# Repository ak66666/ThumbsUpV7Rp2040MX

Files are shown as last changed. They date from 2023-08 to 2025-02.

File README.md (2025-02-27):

# ThumbsUp! v7 RP2040-based keyboard for MX switches

Multilevel 56/58 Key Split Contoured Keyboard.
2- or 3-key Thumb Cluster

* RP2040 is soldered on the boards.
* TRS (3-wire) audio cable to connect the halves.
* Hot swap sockets for MX switches.
* USB-C connectors.
* Connects to computer from either side, halves could be used separately.
* 3 different layouts for the 3-key cluster.

Board needs 3D printed switch plates: https://github.com/ak66666/ThubmsUpSwitchPlates

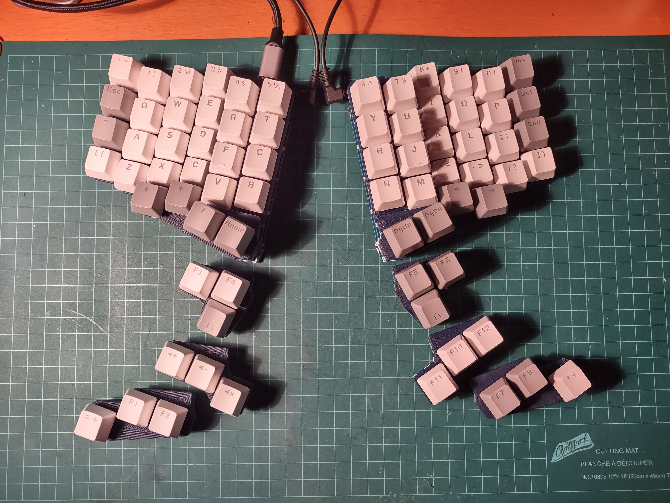
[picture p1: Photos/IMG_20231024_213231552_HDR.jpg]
Main view

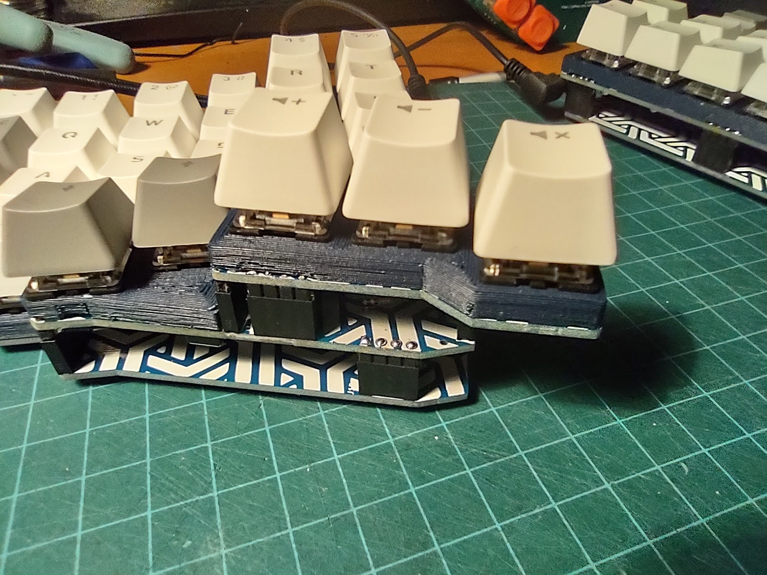
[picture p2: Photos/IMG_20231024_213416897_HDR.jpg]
Some keys are tucked under the middle PCB


Other pictures in Photos folder.

# Firmware

Please refer to this article:
https://thumbsupkeyboards.blogspot.com/2024/02/source-files-and-default-firmware.html

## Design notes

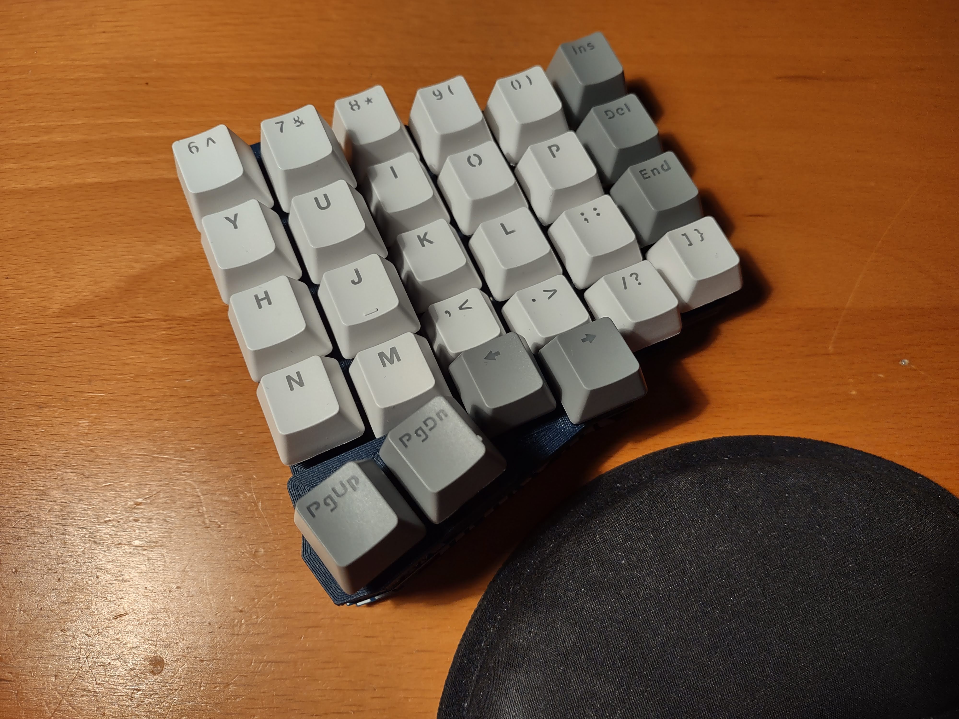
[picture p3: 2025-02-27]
Photos/IMG_20231021_212901962_HDR.jpg

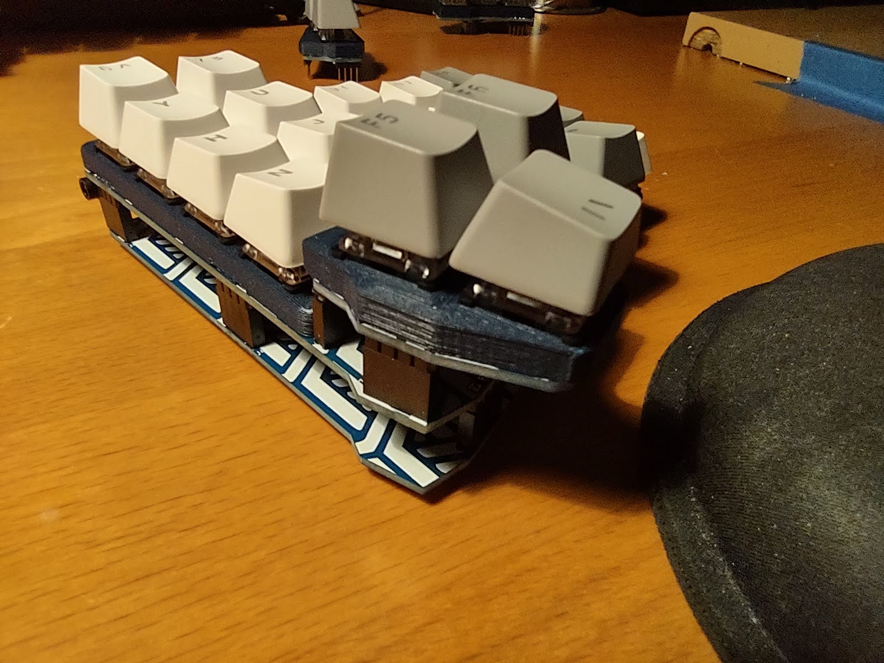
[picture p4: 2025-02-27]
Photos/IMG_20231021_213013907_HDR.jpg

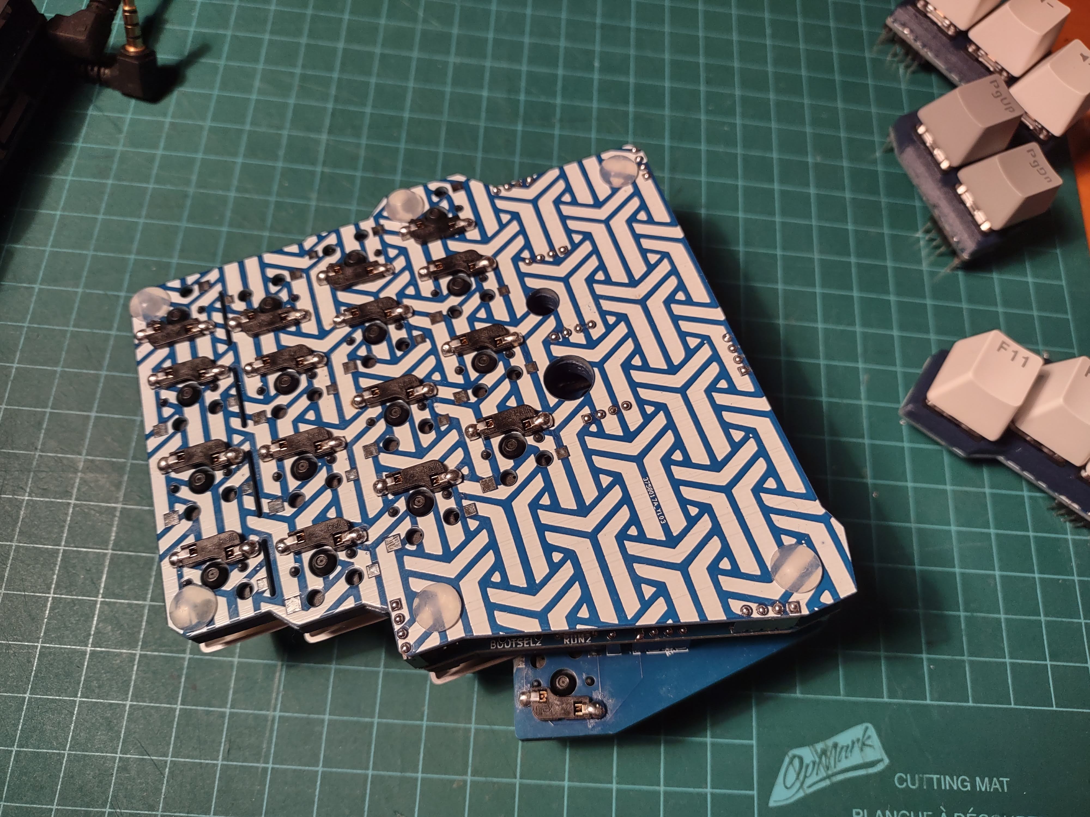
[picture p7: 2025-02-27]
Photos/IMG_20231025_093201816_HDR.jpg

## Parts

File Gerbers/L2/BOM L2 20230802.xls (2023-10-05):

Comment | Designator | Footprint | JLCPCB Part #
W25Q128JVSIM | IC2 | SOIC127P790X216-8N | C2613930
USB_C_Receptacle_USB2.0 | J32 | USB_C_Receptacle_Palconn_UTC16-G | C2927037
27pF | C5,C4 | C_0402_1005Metric | C1557
AMS1117-3.3_SOT223 | U1 | SOT229P700X180-4N | C6186
27.4 | R2,R1 | R_0402_1005Metric | C274349
10uF | C9 | C_0402_1005Metric | C15525
0.1uF | C17,C16,C15,C14,C13,C10,C7,C6,C2 | C_0402_1005Metric | C1525
5.1K | R9,R8,R4 | R_0402_1005Metric | C25905
100uF | C11 | C_1210_3225Metric | C16133
1uF | C12,C3 | C_0402_1005Metric | C52923
Polyfuse | F1 | Fuse_1206_3216Metric | C2836286
1k | R6 | R_0402_1005Metric | C11702
RP2040 | IC1 | QFN40P700X700X90-57N-D | C2040
10K | R3,R7 | R_0402_1005Metric | C25744
ABLS-12.000MHZ-B4-T | Y1 | HC-49S-SMD | C2901753

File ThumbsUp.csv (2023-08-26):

Id | Designator | Package | Quantity | Designation | Supplier and ref
1 | RUN,BOOTSEL | TL1016AAF220QG | 2 | TL1016AAF220QG
2 | IC1 | QFN40P700X700X90-57N-D | 1 | RP2040
3 | D25,D44,D43,D42,D41,D40,D39,D38,D37,D36,D35,D34,D33,D32,D31,D30,D29,D28,D27,D26,D24,D23,D22,D21,D20,D19,D18,D17,D16,D15,D14,D13,D12,D11,D10,D9,D8,D7,D6,D5,D4,D3,D2,D1 | D_SOD-123 | 44 | D_Small
4 | Y1 | HC%2f49US-(AT49)_1 | 1 | ABLS-12.000MHZ-B4-T
5 | R3 | R_0805_2012Metric | 1 | 10k
6 | IC2 | SOIC127P790X216-8N | 1 | W25Q128JVSIM
7 | C9,C11 | C_0805_2012Metric | 2 | 10uF
8 | C7,C6,C2,C1,C17,C16,C15,C14,C13,C10 | C_0805_2012Metric | 10 | 0.1uF
9 | C5,C4 | C_0805_2012Metric | 2 | 27pF
10 | C3,C12 | C_0805_2012Metric | 2 | 1uF
11 | U1 | SOT-223-3_TabPin2 | 1 | NCP1117-3.3_SOT223
12 | R7 | R_0805_2012Metric | 1 | DNF
13 | R6 | R_0805_2012Metric | 1 | 1k
14 | R5,R4 | R_0805_2012Metric | 2 | 4.7k
15 | R2,R1 | R_0805_2012Metric | 2 | 27.4
16 | F1 | Fuse_1206_3216Metric | 1 | Polyfuse
17 | USB1 | Molex-0548190589 | 1 | Molex-0548190589
18 | J27,J24,J25,J26,J6,J4 | PinHeader_1x04_P2.54mm_Vertical | 6 | Conn_01x04_Male
19 | J18,J10,J14 | PinHeader_1x04_P2.54mm_Vertical | 3 | Raiser_Male
20 | MX38 | Kailh_socket_PG1350_optional | 1 | SwMENU
21 | MX27 | Kailh_socket_PG1350_optional | 1 | SwU
22 | MX28 | Kailh_socket_PG1350_optional | 1 | SwJ
23 | MX29 | Kailh_socket_PG1350_optional | 1 | SwM
24 | MX34 | Kailh_socket_PG1350_optional | 1 | SwRALT
25 | J20,J21,J22,J23 | PinSocket_1x04_P2.54mm_Vertical | 4 | Conn_01x04_Female
26 | MX15 | Kailh_socket_PG1350_optional | 1 | SwR
27 | MX24 | Kailh_socket_PG1350_optional | 1 | SwH
28 | MX10 | Kailh_socket_PG1350_optional | 1 | SwLWIN
29 | MX14 | Kailh_socket_PG1350_optional | 1 | SwLALT
30 | MX17 | Kailh_socket_PG1350_optional | 1 | SwV
31 | MX25 | Kailh_socket_PG1350_optional | 1 | SwN
32 | MX19 | Kailh_socket_PG1350_optional | 1 | SwT
33 | MX21 | Kailh_socket_PG1350_optional | 1 | SwB
34 | MX20 | Kailh_socket_PG1350_optional | 1 | SwG
35 | MX23 | Kailh_socket_PG1350_optional | 1 | SwY
36 | MX16 | Kailh_socket_PG1350_optional | 1 | SwF
37 | J15,J11 | PinSocket_1x04_P2.54mm_Vertical | 2 | Raiser_Female

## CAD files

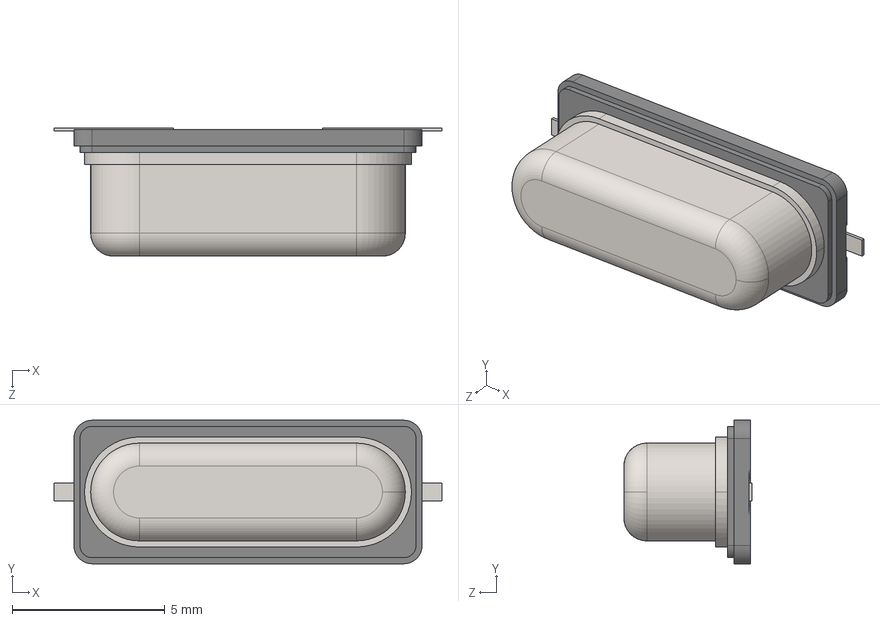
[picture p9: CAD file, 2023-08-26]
ABLS-12.000MHZ-B4-T/3D/ABLS-12.000MHZ-B4-T.stp
12.7 x 4.70 x 4.20 mm

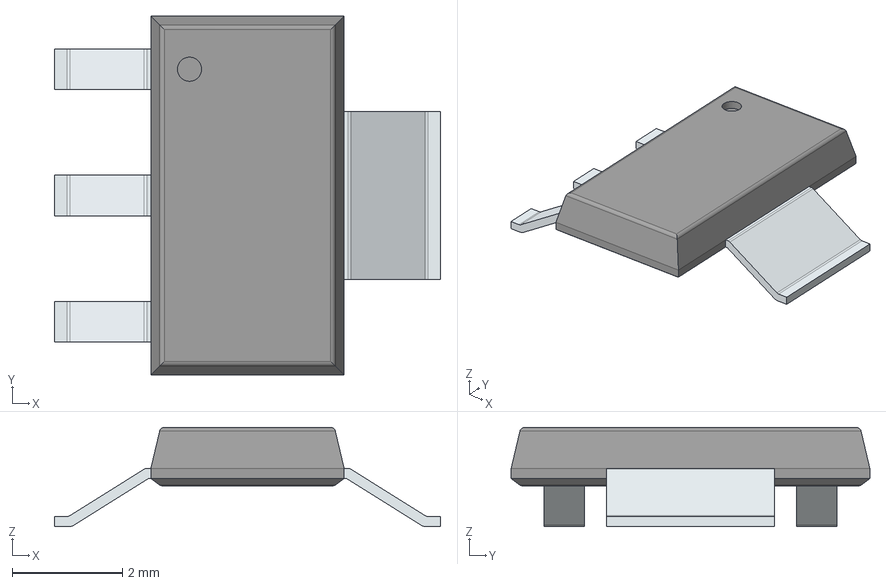
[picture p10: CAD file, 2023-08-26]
AMS1117-3.3/3D/AMS1117-3.3.stp
7.00 x 6.50 x 1.80 mm
PinsArrayL
FilletPinR

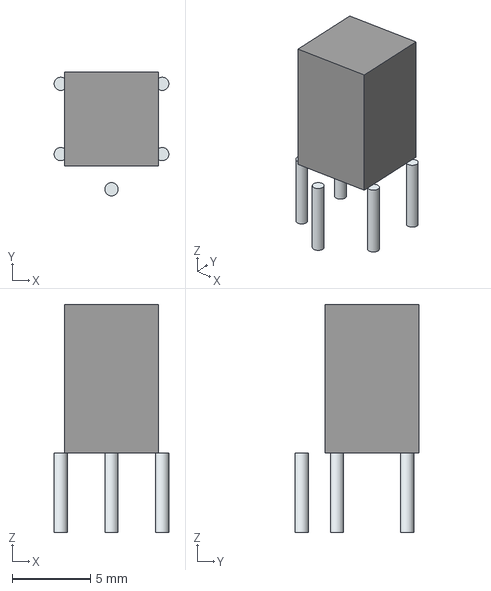
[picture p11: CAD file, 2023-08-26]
LIB_BUTT-4/BUTT-4/3D/BUTT-4.stp
7.35 x 7.92 x 14.6 mm
Leads x 5

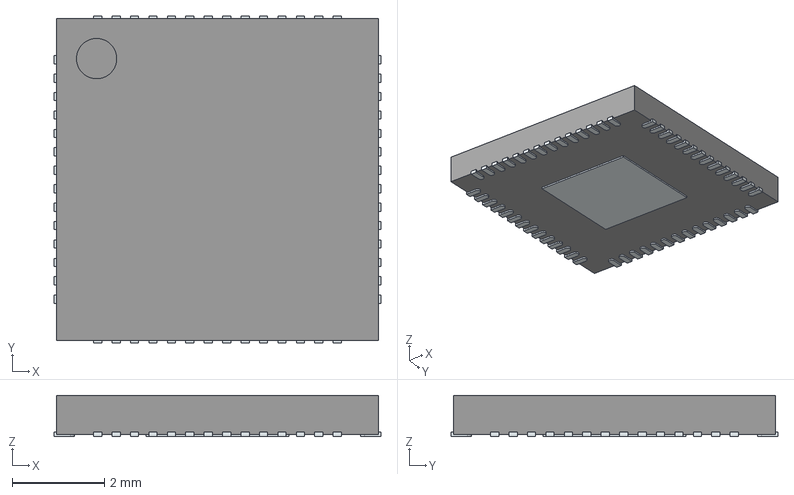
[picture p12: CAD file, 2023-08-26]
RP2040/3D/RP2040.stp
7.10 x 7.10 x 0.9 mm
ThermalPin
PinsArrayLR
PinsArrayTB

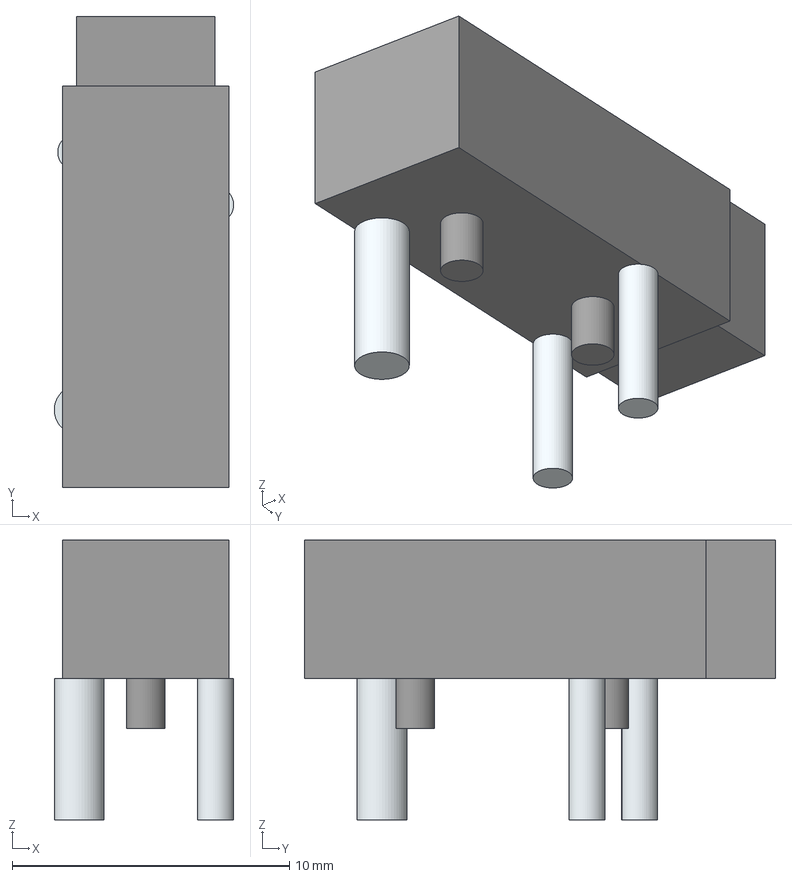
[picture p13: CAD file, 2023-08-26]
STX-3501-3N/3D/STX-3501-3N.stp
6.47 x 17.0 x 10.1 mm
Lugs
Leads

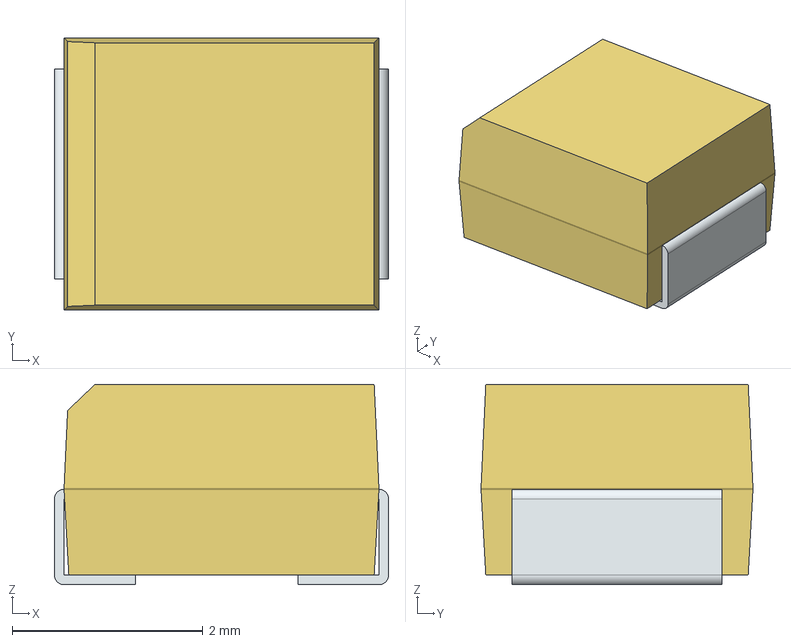
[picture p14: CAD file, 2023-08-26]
TAJB107K006RNJV/3D/TAJB107K006RNJV.stp
3.50 x 2.85 x 2.10 mm
FilletPin1
FilletPin2

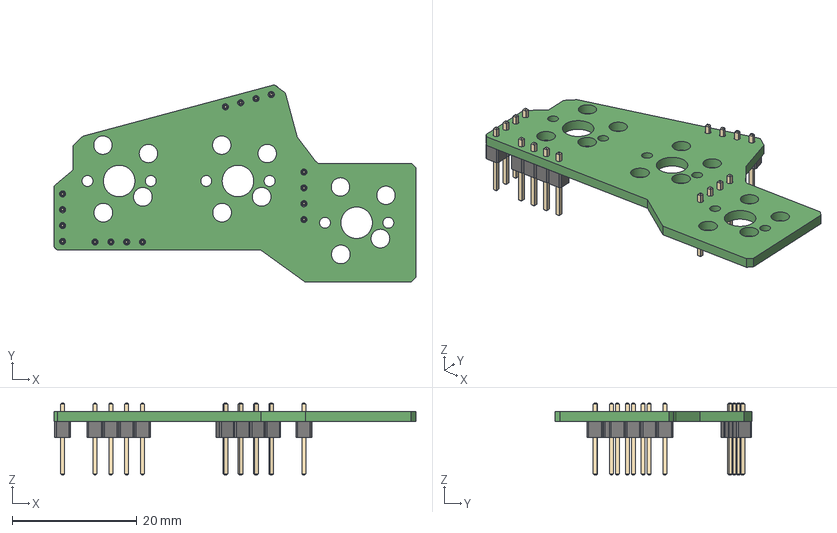
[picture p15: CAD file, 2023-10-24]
ThumbsUp.step
58.1 x 31.7 x 11.5 mm

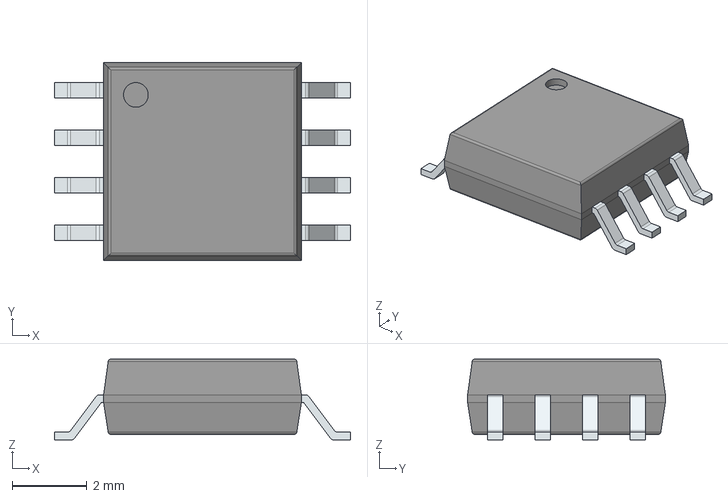
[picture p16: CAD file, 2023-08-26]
W25Q128JVSIM/3D/W25Q128JVSIM.stp
7.90 x 5.28 x 2.16 mm
PinsArrayLR

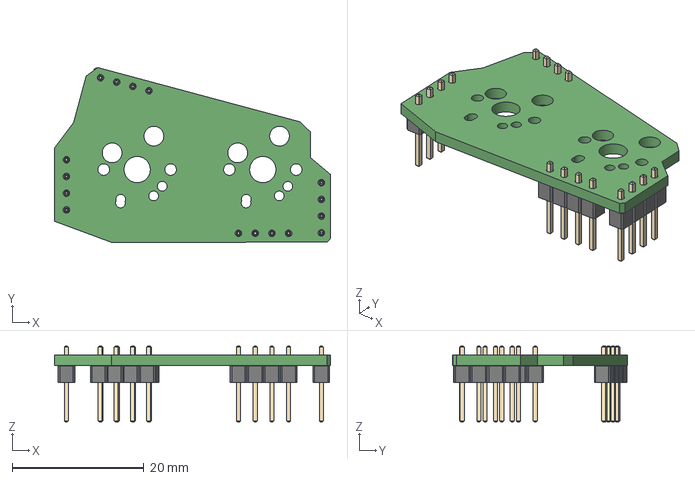
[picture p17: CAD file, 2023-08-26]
ThumbsUp 3.step
41.9 x 26.6 x 11.5 mm

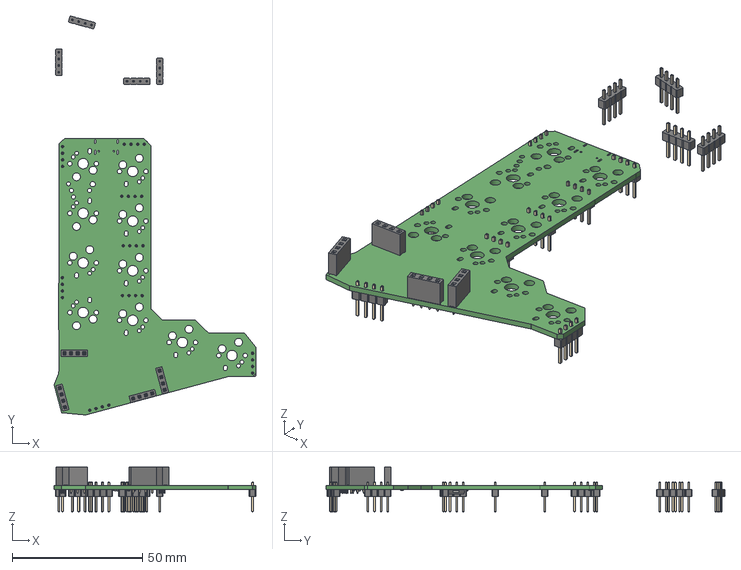
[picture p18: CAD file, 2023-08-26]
ThumbsUp 2.step
77.5 x 153.2 x 17.2 mm

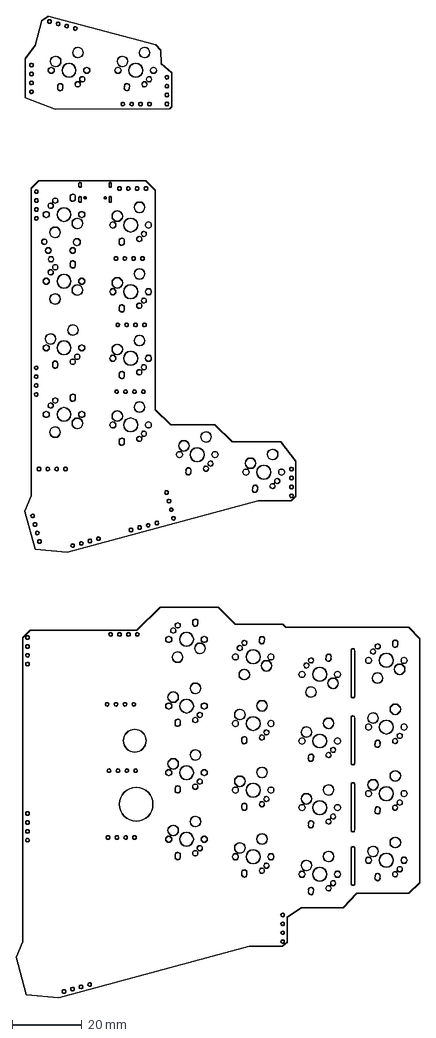
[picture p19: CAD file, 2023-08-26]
Outline.dxf
115.4 x 280.8 mm

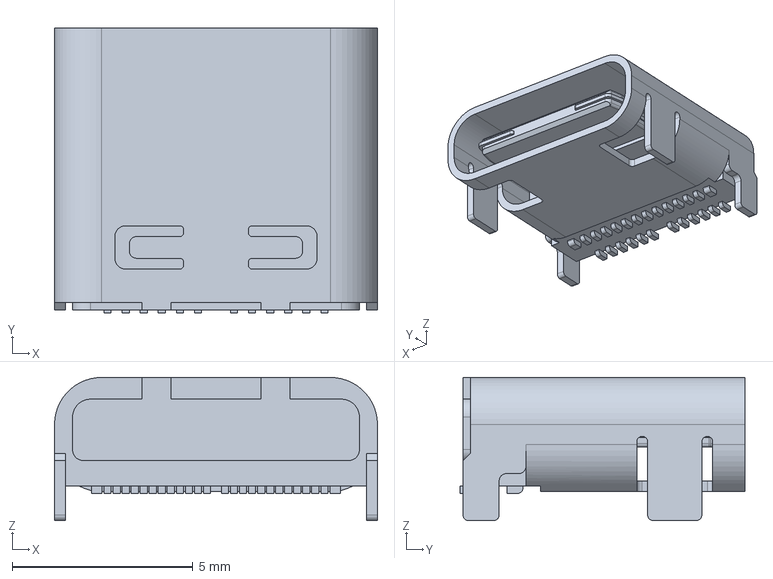
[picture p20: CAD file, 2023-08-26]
105450-0101/3D/105450-0101.stp
8.94 x 7.90 x 3.96 mm

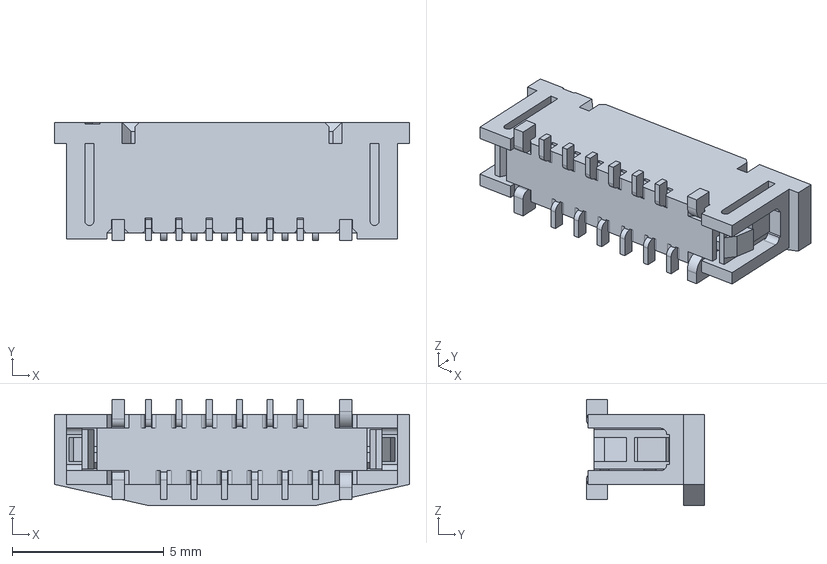
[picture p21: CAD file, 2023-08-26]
Molex 52559-1233/52559-1233/3D/52559-1233.stp
11.7 x 3.90 x 3.50 mm

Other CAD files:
Outline/Case v7 v5.3mf
ABLS-12.000MHZ-B4-T/Allegro/hc_49us-_at49__1.psm
ABLS-12.000MHZ-B4-T/DEHDL/abls_12.000mhz_b4_t/chips/chips.prt
AMS1117-3.3/Allegro/sot229p700x180-4n.psm
AMS1117-3.3/DEHDL/ams1117_3.3/chips/chips.prt
EVQ-P7B01P/Allegro/evqp7b01p.psm
EVQ-P7B01P/DEHDL/evq_p7b01p/chips/chips.prt
LIB_BUTT-4/BUTT-4/Allegro/butt4.psm
LIB_BUTT-4/BUTT-4/DEHDL/butt_4/chips/chips.prt
Molex 52559-1233/52559-1233/Allegro/525591233.psm
Molex 52559-1233/52559-1233/DEHDL/52559_1233/chips/chips.prt
Outline/Case v7 v5.f3d
Outline/Case v7 v5.ipt
Outline/Case v7 v5.skp
RP2040/Allegro/qfn40p700x700x90-57n-d.psm
RP2040/DEHDL/rp2040/chips/chips.prt
STX-3501-3N/Allegro/stx35013n.psm
STX-3501-3N/DEHDL/stx_3501_3n/chips/chips.prt
TAJB107K006RNJV/Allegro/cappm3528x210n.psm
TAJB107K006RNJV/DEHDL/tajb107k006rnjv/chips/chips.prt
TL1016AAF220QG/Allegro/tl1016aaf220qg.psm
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

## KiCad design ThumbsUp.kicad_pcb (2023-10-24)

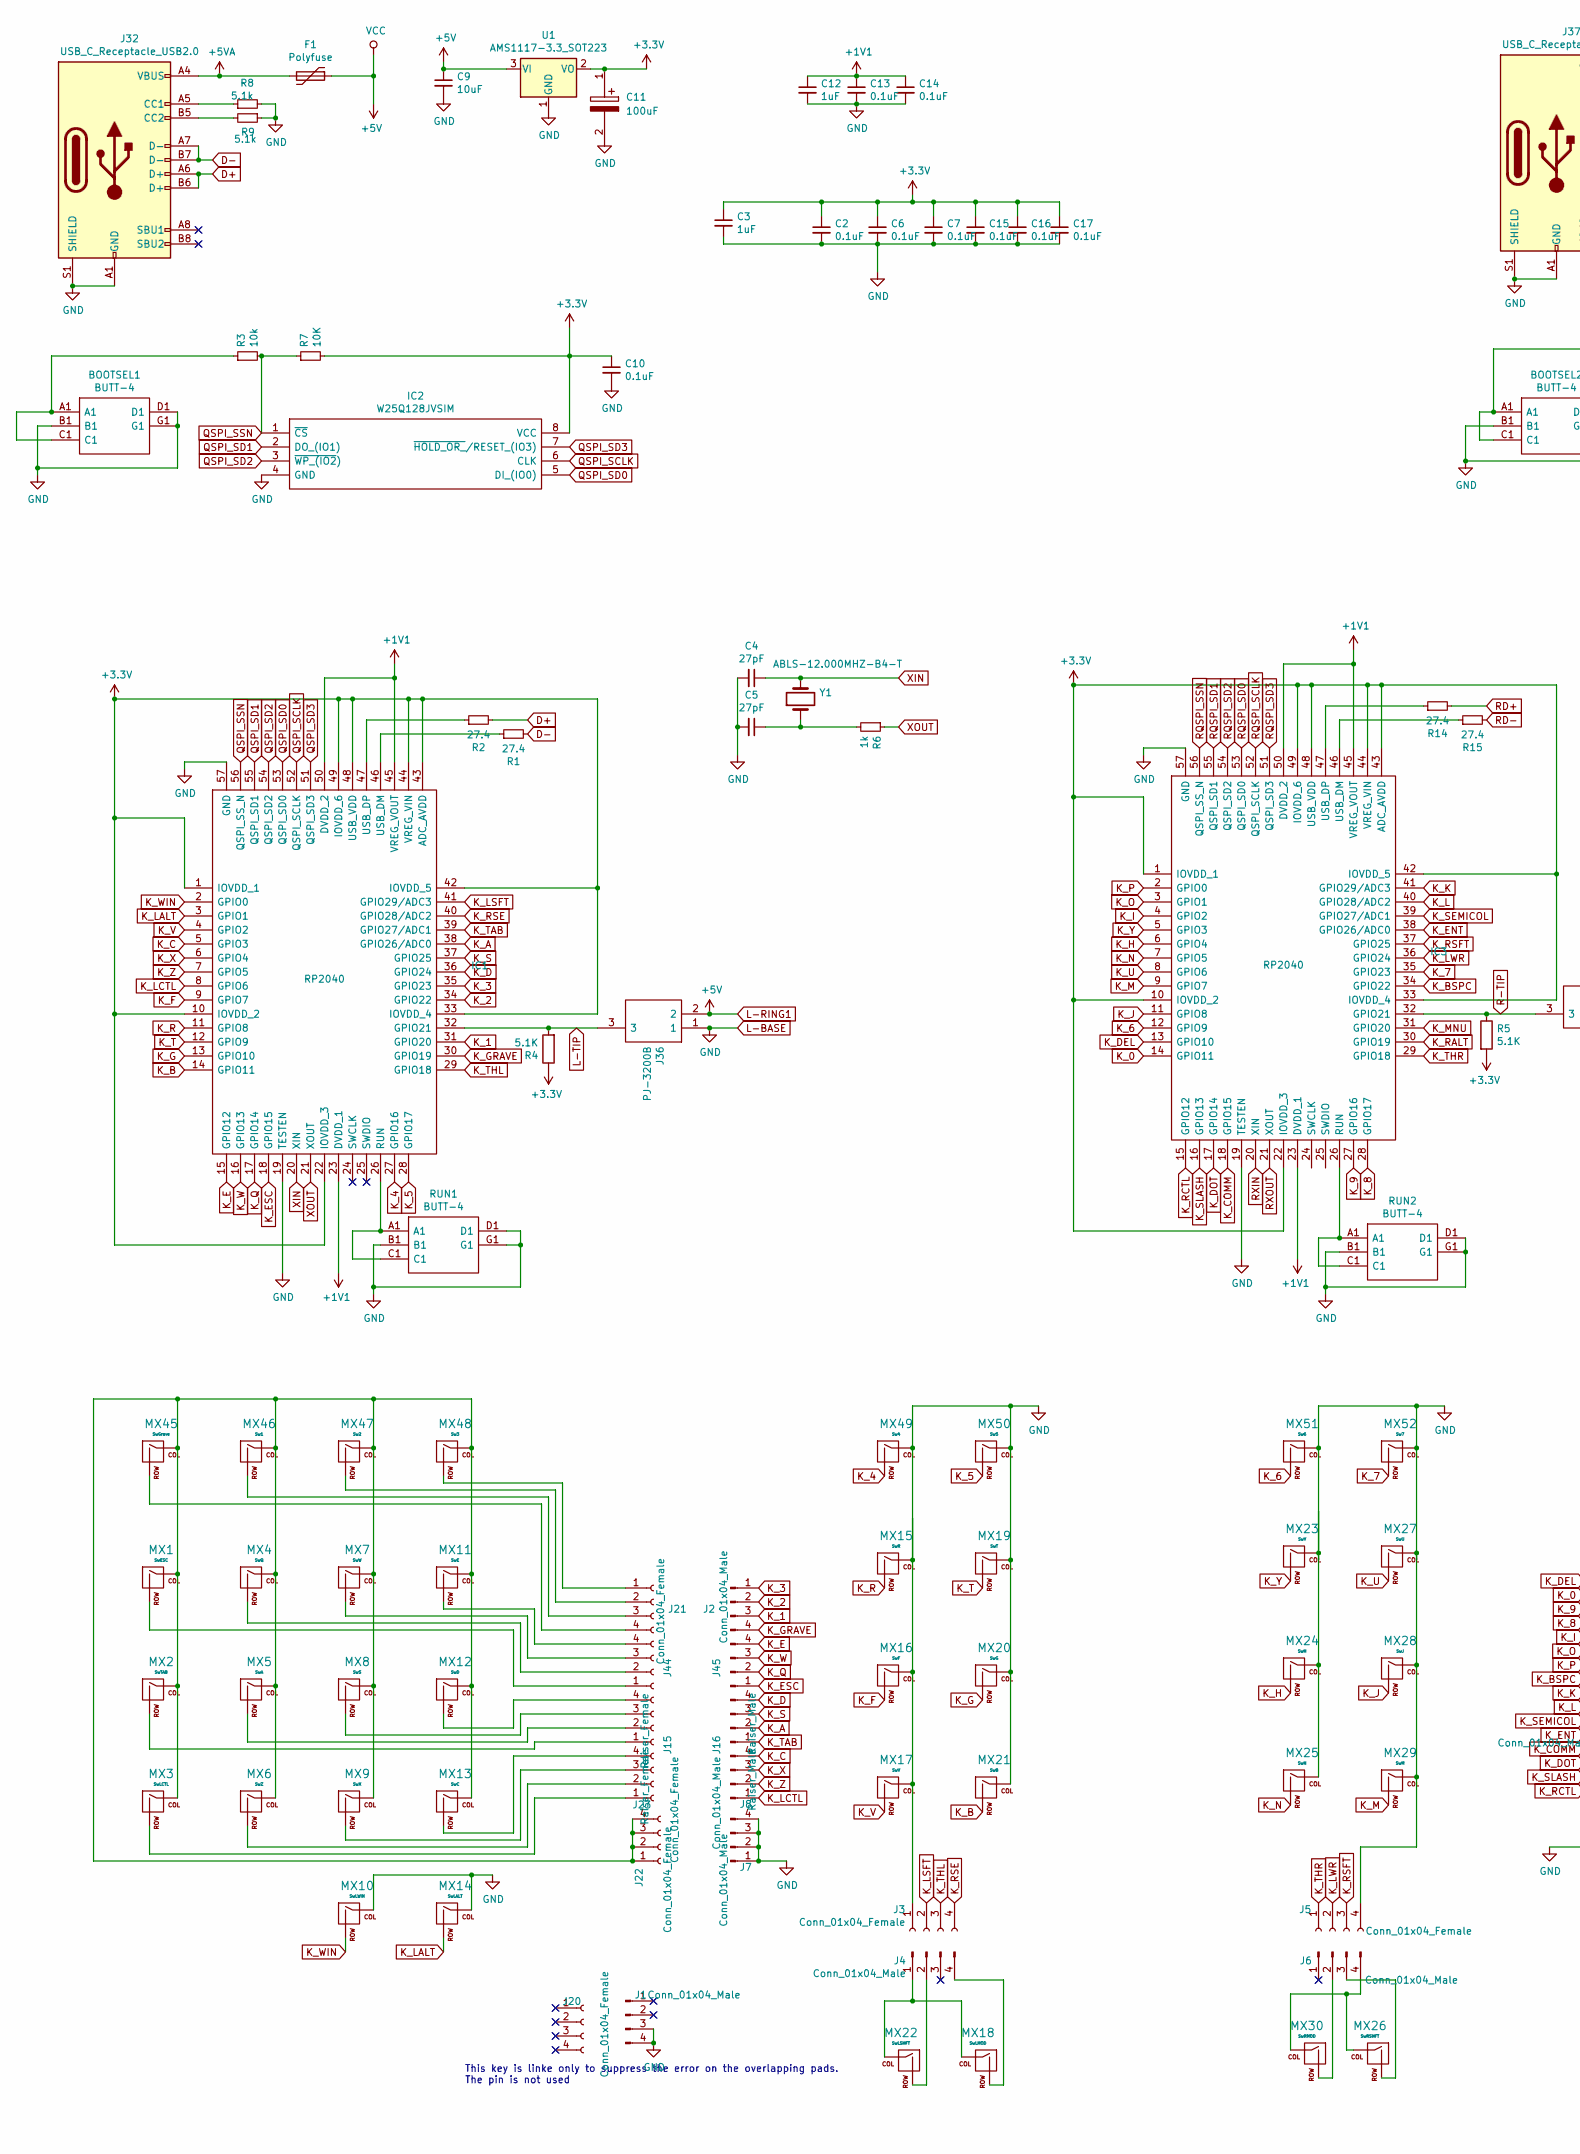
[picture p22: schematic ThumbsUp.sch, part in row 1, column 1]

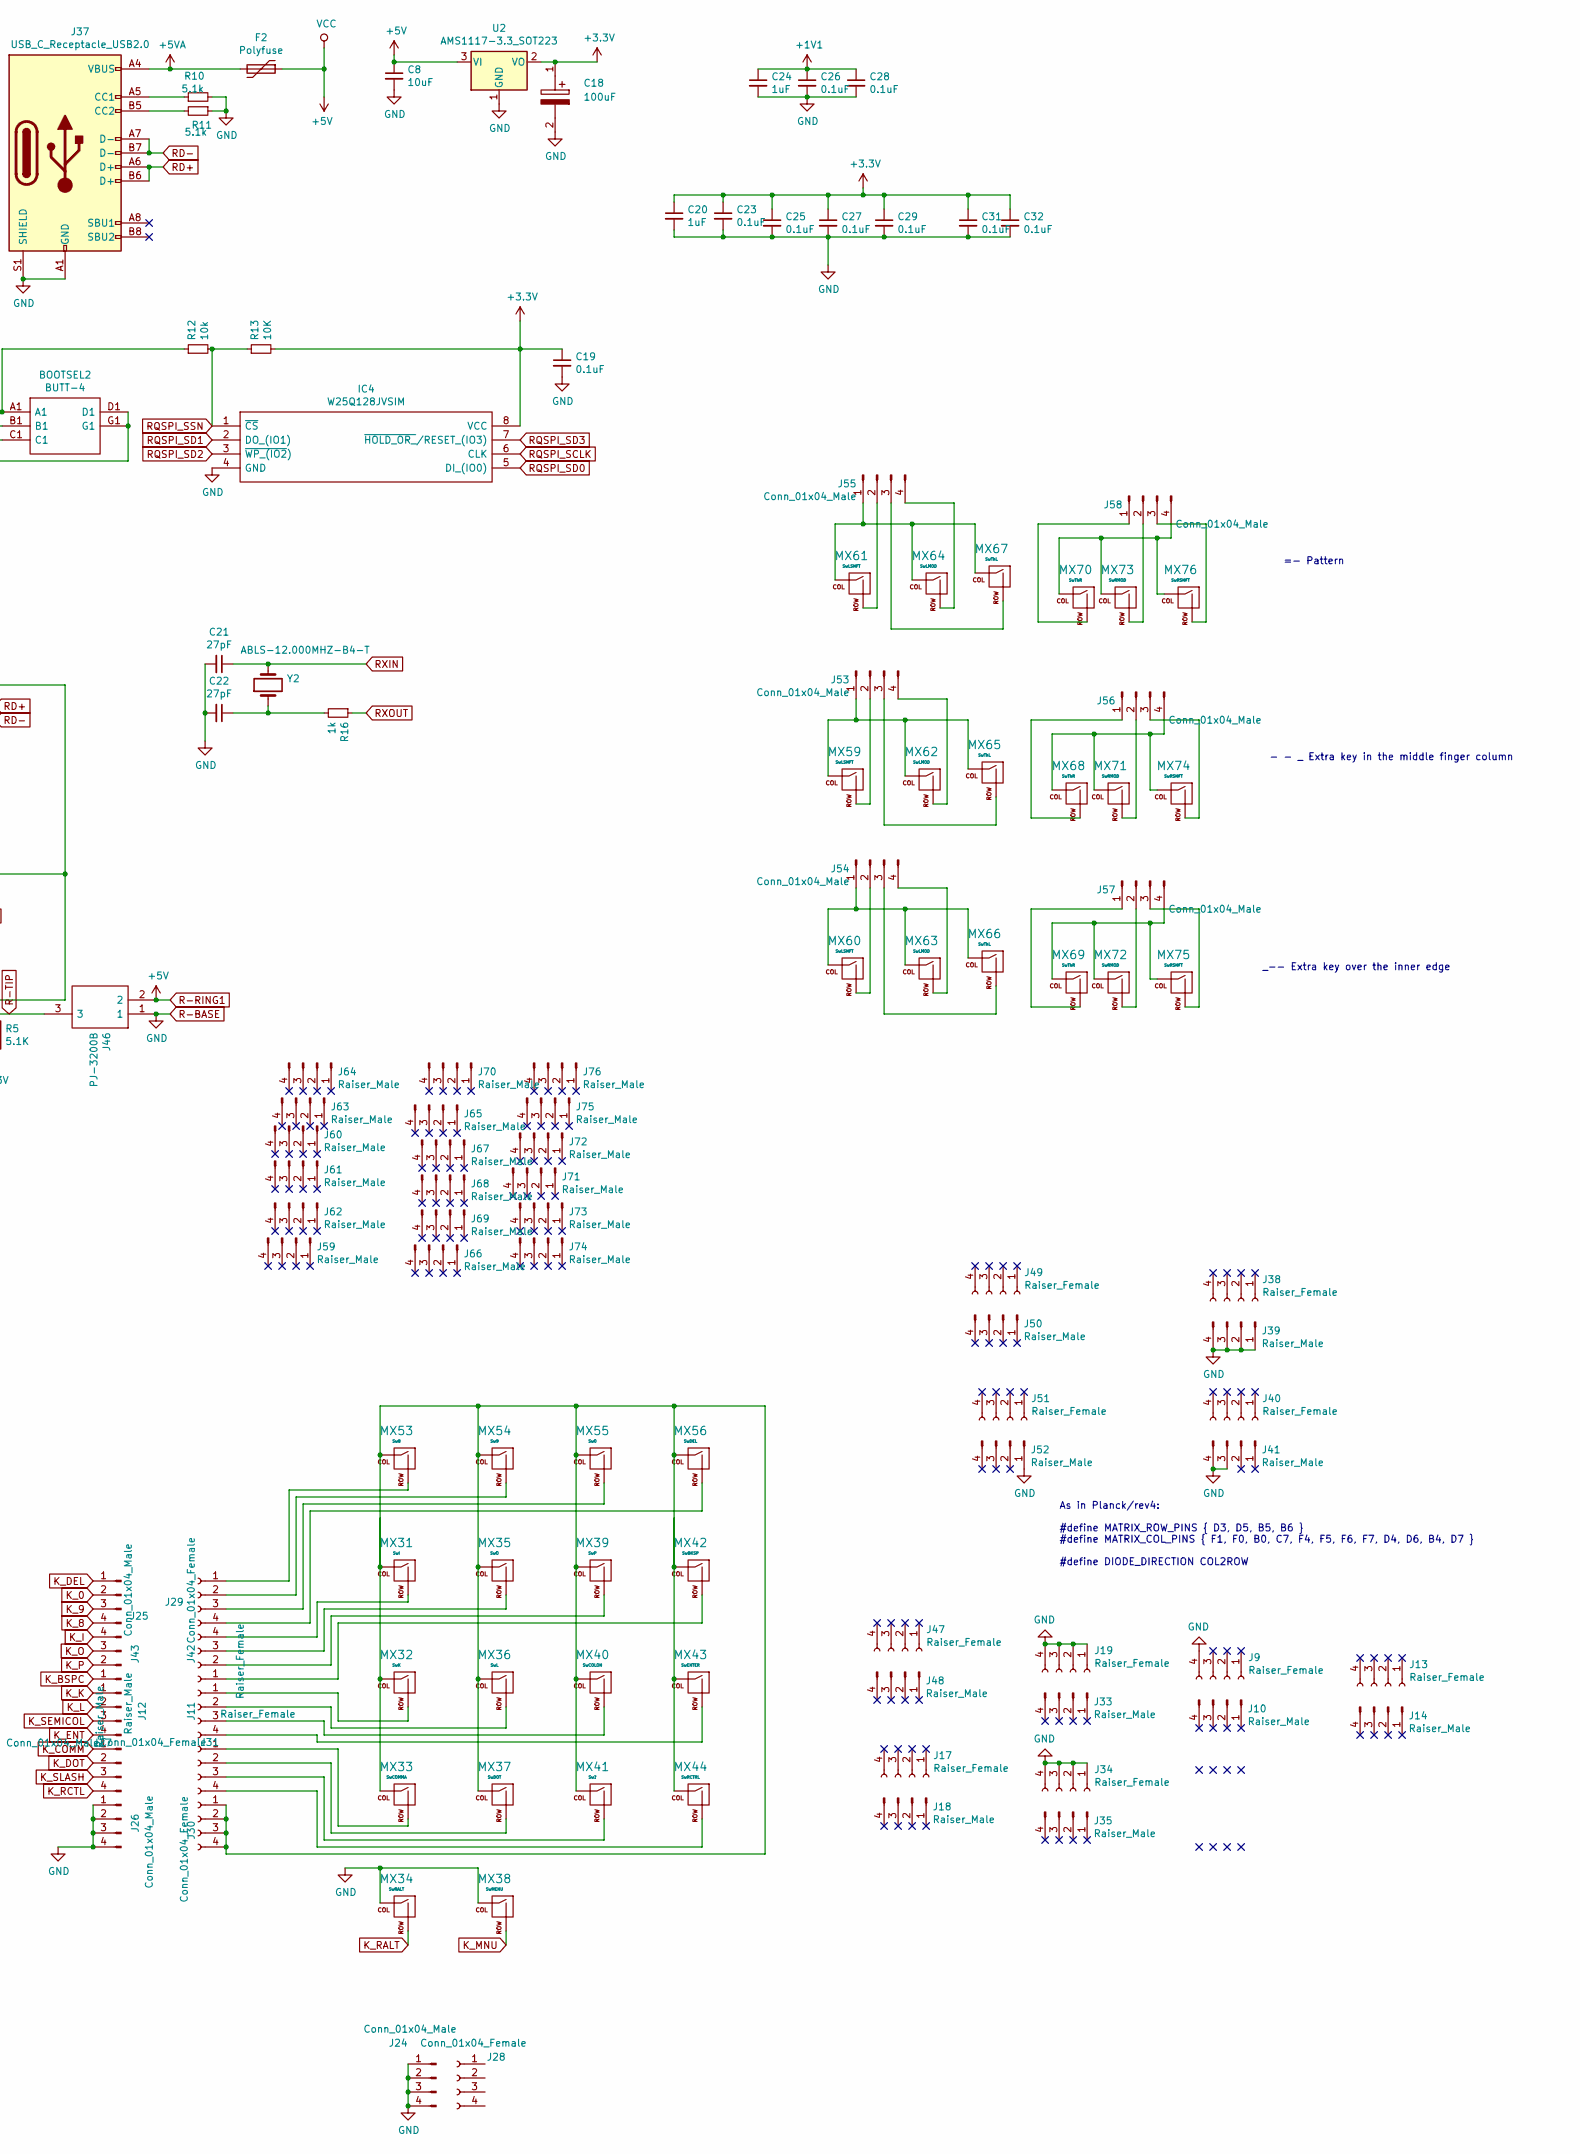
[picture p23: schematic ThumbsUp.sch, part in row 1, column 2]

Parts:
BOOTSEL1, BOOTSEL2: BUTT-4; BUTT4; Manufacturer_Part_Number BUTT-4; Mouser Part Number 992-BUTT-4
C2, C6, C7, C10, C13, C14, C15, C16, C17, C19, C23, C25, C26, C27, C28, C29, C31, C32: 0.1uF; C_0402_1005Metric
C3, C12, C20, C24: 1uF; C_0402_1005Metric
C4, C5, C21, C22: 27pF; C_0402_1005Metric
C8, C9: 10uF; C_0402_1005Metric
C11, C18: 100uF; C_1210_3225Metric
F1, F2: Polyfuse; Fuse_1206_3216Metric
IC1, IC3: RP2040; RP2040-QFN-56; Manufacturer_Part_Number RP2040
IC2, IC4: W25Q128JVSIM; SOIC127P790X216-8N; Manufacturer_Part_Number W25Q128JVSIM; Mouser Part Number 454-W25Q128JVSIM
J1, J2, J4, J6, J7, J8, J24, J25, J26, J27, J53, J54, J55, J56, J57, J58: Conn_01x04_Male; PinHeader_1x04_P2.54mm_Vertical
J3, J5, J20, J21, J22, J23, J28, J29, J30, J31: Conn_01x04_Female; PinSocket_1x04_P2.54mm_Vertical
J9, J11, J13, J15, J17, J19, J34, J38, J40, J42, J44, J47, J49, J51: Raiser_Female; PinSocket_1x04_P2.54mm_Vertical
J10, J12, J14, J16, J18, J33, J35, J39, J41, J43, J45, J48, J50, J52, J59, J60, J61, J62, J63, J64, J65, J66, J67, J68, J69, J70, J71, J72, J73, J74, J75, J76: Raiser_Male; PinHeader_1x04_P2.54mm_Vertical
J32, J37: USB_C_Receptacle_USB2.0; USB_C_Receptacle_Palconn_UTC16-G
J36, J46: PJ-3200B; PJ-3200B-4A; Manufacturer_Part_Number STX-3501-3N; Mouser Part Number 806-STX-3501-3N
MX1: SwESC; MX-GLP2-HotSwap
MX2: SwTAB; MX-GLP2-HotSwap
MX3: SwLCTL; MX-GLP2-HotSwap
MX4: SwQ; MX-GLP2-HotSwap
MX5: SwA; MX-GLP2-HotSwap
MX6: SwZ; MX-GLP2-HotSwap
MX7: SwW; MX-GLP2-HotSwap
MX8: SwS; MX-GLP2-HotSwap
MX9: SwX; MX-GLP2-HotSwap
MX10: SwLWIN; MX-GLP2-HotSwap
MX11: SwE; MX-GLP2-HotSwap
MX12: SwD; MX-GLP2-HotSwap
MX13: SwC; MX-GLP2-HotSwap
MX14: SwLALT; MX-GLP2-HotSwap
MX15: SwR; MX-GLP2-HotSwap
MX16: SwF; MX-GLP2-HotSwap
MX17: SwV; MX-GLP2-HotSwap
MX18, MX62, MX63, MX64: SwLMOD; MX-GLP2-HotSwap
MX19: SwT; MX-GLP2-HotSwap
MX20: SwG; MX-GLP2-HotSwap
MX21: SwB; MX-GLP2-HotSwap
MX22, MX59, MX60, MX61: SwLSHFT; MX-GLP2-HotSwap
MX23: SwY; MX-GLP2-HotSwap
MX24: SwH; MX-GLP2-HotSwap
MX25: SwN; MX-GLP2-HotSwap
MX26, MX74, MX75, MX76: SwRSHFT; MX-GLP2-HotSwap
MX27: SwU; MX-GLP2-HotSwap
MX28: SwJ; MX-GLP2-HotSwap
MX29: SwM; MX-GLP2-HotSwap
MX30, MX71, MX72, MX73: SwRMOD; MX-GLP2-HotSwap
MX31: SwI; MX-GLP2-HotSwap
MX32: SwK; MX-GLP2-HotSwap
MX33: SwCOMMA; MX-GLP2-HotSwap
MX34: SwRALT; MX-GLP2-HotSwap
MX35: SwO; MX-GLP2-HotSwap
MX36: SwL; MX-GLP2-HotSwap
MX37: SwDOT; MX-GLP2-HotSwap
MX38: SwMENU; MX-GLP2-HotSwap
MX39: SwP; MX-GLP2-HotSwap
MX40: SwCOLON; MX-GLP2-HotSwap
MX41: Sw?; MX-GLP2-HotSwap
MX42: SwBKSP; MX-GLP2-HotSwap
MX43: SwENTER; MX-GLP2-HotSwap
MX44: SwRCTRL; MX-GLP2-HotSwap
MX45: SwGrave; MX-GLP2-HotSwap
MX46: Sw1; MX-GLP2-HotSwap
MX47: Sw2; MX-GLP2-HotSwap
MX48: Sw3; MX-GLP2-HotSwap
MX49: Sw4; MX-GLP2-HotSwap
MX50: Sw5; MX-GLP2-HotSwap
MX51: Sw6; MX-GLP2-HotSwap
MX52: Sw7; MX-GLP2-HotSwap
MX53: Sw8; MX-GLP2-HotSwap
MX54: Sw9; MX-GLP2-HotSwap
MX55: Sw0; MX-GLP2-HotSwap
MX56: SwDEL; MX-GLP2-HotSwap
MX65, MX66, MX67: SwThL; MX-GLP2-HotSwap
MX68, MX69, MX70: SwThR; MX-GLP2-HotSwap
R1, R2, R14, R15: 27.4; R_0402_1005Metric
R3, R12: 10k; R_0402_1005Metric
R4, R5: 5.1K; R_0402_1005Metric
R6, R16: 1k; R_0402_1005Metric
R7, R13: 10K; R_0402_1005Metric
R8, R9, R10, R11: 5.1k; R_0402_1005Metric
RUN1, RUN2: BUTT-4; BUTT4; Manufacturer_Part_Number BUTT-4; Mouser Part Number 992-BUTT-4
U1, U2: AMS1117-3.3_SOT223; SOT229P700X180-4N
Y1, Y2: ABLS-12.000MHZ-B4-T; HC%2f49US-(AT49)_1

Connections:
+1V1: C12.1, C13.1, C14.1, C24.1, C26.1, C28.1, IC1.23 (DVDD_1), IC1.45 (VREG_VOUT), IC1.50 (DVDD_2), IC3.23 (DVDD_1), IC3.45 (VREG_VOUT), IC3.50 (DVDD_2)
+3V3: C2.1, C3.1, C6.1, C7.1, C10.1, C11.1, C15.1, C16.1, C17.1, C18.1, C19.1, C20.1, C23.1, C25.1, C27.1, C29.1, C31.1, C32.1, IC1.1 (IOVDD_1), IC1.10 (IOVDD_2), IC1.22 (IOVDD_3), IC1.33 (IOVDD_4), IC1.42 (IOVDD_5), IC1.43 (ADC_AVDD), IC1.44 (VREG_VIN), IC1.48 (USB_VDD), IC1.49 (IOVDD_6), IC2.8 (VCC), IC3.1 (IOVDD_1), IC3.10 (IOVDD_2), IC3.22 (IOVDD_3), IC3.33 (IOVDD_4), IC3.42 (IOVDD_5), IC3.43 (ADC_AVDD), IC3.44 (VREG_VIN), IC3.48 (USB_VDD), IC3.49 (IOVDD_6), IC4.8 (VCC), R4.1, R5.2, R7.2, R13.2, U1.2 (VO), U2.2 (VO)
+5VA: F1.2, F2.2, J32.A4 (VBUS), J32.A9 (VBUS), J32.B4 (VBUS), J32.B9 (VBUS), J37.A4 (VBUS), J37.A9 (VBUS), J37.B4 (VBUS), J37.B9 (VBUS)
D+: J32.A6 (D+), J32.B6 (D+), R2.2
D-: J32.A7 (D-), J32.B7 (D-), R1.2
K_0: IC3.14 (GPIO11), J25.2
K_1: IC1.31 (GPIO20), J2.3
K_2: IC1.34 (GPIO22), J2.2
K_3: IC1.35 (GPIO23), J2.1
K_4: IC1.27 (GPIO16), MX49.2 (ROW)
K_5: IC1.28 (GPIO17), MX50.2 (ROW)
K_6: IC3.12 (GPIO9), MX51.2 (ROW)
K_7: IC3.35 (GPIO23), MX52.2 (ROW)
K_8: IC3.28 (GPIO17), J25.4
K_9: IC3.27 (GPIO16), J25.3
K_A: IC1.38 (GPIO26/ADC0), J16.2
K_B: IC1.14 (GPIO11), MX21.2 (ROW)
K_BSPC: IC3.34 (GPIO22), J43.1
K_C: IC1.5 (GPIO3), J8.4
K_COMM: IC3.18 (GPIO15), J27.1
K_D: IC1.36 (GPIO24), J16.4
K_DEL: IC3.13 (GPIO10), J25.1
K_DOT: IC3.17 (GPIO14), J27.2
K_E: IC1.15 (GPIO12), J45.4
K_ENT: IC3.38 (GPIO26/ADC0), J12.4
K_ESC: IC1.18 (GPIO15), J45.1
K_F: IC1.9 (GPIO7), MX16.2 (ROW)
K_G: IC1.13 (GPIO10), MX20.2 (ROW)
K_GRAVE: IC1.30 (GPIO19), J2.4
K_H: IC3.6 (GPIO4), MX24.2 (ROW)
K_I: IC3.4 (GPIO2), J43.4
K_J: IC3.11 (GPIO8), MX28.2 (ROW)
K_K: IC3.41 (GPIO29/ADC3), J12.1
K_L: IC3.40 (GPIO28/ADC2), J12.2
K_LALT: IC1.3 (GPIO1), MX14.2 (ROW)
K_LCTL: IC1.8 (GPIO6), J8.1
K_LSFT: IC1.41 (GPIO29/ADC3), J3.2
K_LWR: IC3.36 (GPIO24), J5.2
K_M: IC3.9 (GPIO7), MX29.2 (ROW)
K_MNU: IC3.31 (GPIO20), MX38.2 (ROW)
K_N: IC3.7 (GPIO5), MX25.2 (ROW)
K_O: IC3.3 (GPIO1), J43.3
K_P: IC3.2 (GPIO0), J43.2
K_Q: IC1.17 (GPIO14), J45.2
K_R: IC1.11 (GPIO8), MX15.2 (ROW)
K_RALT: IC3.30 (GPIO19), MX34.2 (ROW)
K_RCTL: IC3.15 (GPIO12), J27.4
K_RSE: IC1.40 (GPIO28/ADC2), J3.4
K_RSFT: IC3.37 (GPIO25), J5.3
K_S: IC1.37 (GPIO25), J16.3
K_SEMICOL: IC3.39 (GPIO27/ADC1), J12.3
K_SLASH: IC3.16 (GPIO13), J27.3
K_T: IC1.12 (GPIO9), MX19.2 (ROW)
K_TAB: IC1.39 (GPIO27/ADC1), J16.1
K_THL: IC1.29 (GPIO18), J3.3
K_THR: IC3.29 (GPIO18), J5.1
K_U: IC3.8 (GPIO6), MX27.2 (ROW)
K_V: IC1.4 (GPIO2), MX17.2 (ROW)
K_W: IC1.16 (GPIO13), J45.3
K_WIN: IC1.2 (GPIO0), MX10.2 (ROW)
K_X: IC1.6 (GPIO4), J8.3
K_Y: IC3.5 (GPIO3), MX23.2 (ROW)
K_Z: IC1.7 (GPIO5), J8.2
L-BASE: BOOTSEL1.B1, BOOTSEL1.D1, BOOTSEL1.G1, BOOTSEL2.B1, BOOTSEL2.D1, BOOTSEL2.G1, C2.2, C3.2, C4.2, C5.2, C6.2, C7.2, C8.2, C9.2, C10.2, C11.2, C12.2, C13.2, C14.2, C15.2, C16.2, C17.2, C18.2, C19.2, C20.2, C21.2, C22.2, C23.2, C24.2, C25.2, C26.2, C27.2, C28.2, C29.2, C31.2, C32.2, IC1.19 (TESTEN), IC1.57 (GND), IC2.4 (GND), IC3.19 (TESTEN), IC3.57 (GND), IC4.4 (GND), J1.3, J1.4, J3.1, J5.4, J7.1, J7.2, J7.3, J7.4, J9.4, J19.1, J19.2, J19.3, J19.4, J24.1, J24.2, J24.3, J24.4, J26.1, J26.2, J26.3, J26.4, J32.A1 (GND), J32.A12 (GND), J32.B1 (GND), J32.B12 (GND), J32.S1 (SHIELD), J34.1, J34.2, J34.3, J34.4, J36.1, J37.A1 (GND), J37.A12 (GND), J37.B1 (GND), J37.B12 (GND), J37.S1 (SHIELD), J39.1, J39.2, J39.3, J39.4, J41.3, J41.4, J46.1, J52.1, MX10.1 (COL), MX14.1 (COL), MX15.1 (COL), MX16.1 (COL), MX17.1 (COL), MX19.1 (COL), MX20.1 (COL), MX21.1 (COL), MX23.1 (COL), MX24.1 (COL), MX25.1 (COL), MX27.1 (COL), MX28.1 (COL), MX29.1 (COL), MX34.1 (COL), MX38.1 (COL), MX49.1 (COL), MX50.1 (COL), MX51.1 (COL), MX52.1 (COL), R8.2, R9.1, R10.2, R11.1, RUN1.B1, RUN1.D1, RUN1.G1, RUN2.B1, RUN2.D1, RUN2.G1, U1.1 (GND), U2.1 (GND)
L-RING1: C8.1, C9.1, F1.1, F2.1, J36.2, J46.2, U1.3 (VI), U2.3 (VI)
L-TIP: IC1.32 (GPIO21), J36.3, R4.2
unnamed: BOOTSEL1.A1, BOOTSEL1.C1, R3.1
unnamed: BOOTSEL2.A1, BOOTSEL2.C1, R12.1
unnamed: C5.1, R6.2, Y1.1
unnamed: C22.1, R16.2, Y2.1
unnamed: IC1.26 (RUN), RUN1.A1, RUN1.C1
unnamed: IC1.46 (USB_DM), R1.1
unnamed: IC1.47 (USB_DP), R2.1
unnamed: IC3.26 (RUN), RUN2.A1, RUN2.C1
unnamed: IC3.46 (USB_DM), R15.1
unnamed: IC3.47 (USB_DP), R14.1
unnamed: J4.1, MX18.1 (COL), MX22.1 (COL)
unnamed: J4.2, MX22.2 (ROW)
unnamed: J4.4, MX18.2 (ROW)
unnamed: J6.2, MX30.2 (ROW)
unnamed: J6.3, MX26.2 (ROW)
unnamed: J6.4, MX26.1 (COL), MX30.1 (COL)
unnamed: J11.1, MX32.2 (ROW)
unnamed: J11.2, MX36.2 (ROW)
unnamed: J11.3, MX40.2 (ROW)
unnamed: J11.4, MX43.2 (ROW)
unnamed: J15.1, MX2.2 (ROW)
unnamed: J15.2, MX5.2 (ROW)
unnamed: J15.3, MX8.2 (ROW)
unnamed: J15.4, MX12.2 (ROW)
unnamed: J21.1, MX48.2 (ROW)
unnamed: J21.2, MX47.2 (ROW)
unnamed: J21.3, MX46.2 (ROW)
unnamed: J21.4, MX45.2 (ROW)
unnamed: J22.1, J22.2, J22.3, J22.4, MX1.1 (COL), MX2.1 (COL), MX3.1 (COL), MX4.1 (COL), MX5.1 (COL), MX6.1 (COL), MX7.1 (COL), MX8.1 (COL), MX9.1 (COL), MX11.1 (COL), MX12.1 (COL), MX13.1 (COL), MX45.1 (COL), MX46.1 (COL), MX47.1 (COL), MX48.1 (COL)
unnamed: J23.1, MX3.2 (ROW)
unnamed: J23.2, MX6.2 (ROW)
unnamed: J23.3, MX9.2 (ROW)
unnamed: J23.4, MX13.2 (ROW)
unnamed: J29.1, MX53.2 (ROW)
unnamed: J29.2, MX54.2 (ROW)
unnamed: J29.3, MX55.2 (ROW)
unnamed: J29.4, MX56.2 (ROW)
unnamed: J30.1, J30.2, J30.3, J30.4, MX31.1 (COL), MX32.1 (COL), MX33.1 (COL), MX35.1 (COL), MX36.1 (COL), MX37.1 (COL), MX39.1 (COL), MX40.1 (COL), MX41.1 (COL), MX42.1 (COL), MX43.1 (COL), MX44.1 (COL), MX53.1 (COL), MX54.1 (COL), MX55.1 (COL), MX56.1 (COL)
unnamed: J31.1, MX33.2 (ROW)
unnamed: J31.2, MX37.2 (ROW)
unnamed: J31.3, MX41.2 (ROW)
unnamed: J31.4, MX44.2 (ROW)
unnamed: J32.A5 (CC1), R8.1
unnamed: J32.B5 (CC2), R9.2
unnamed: J37.A5 (CC1), R10.1
unnamed: J37.B5 (CC2), R11.2
unnamed: J42.1, MX42.2 (ROW)
unnamed: J42.2, MX39.2 (ROW)
unnamed: J42.3, MX35.2 (ROW)
unnamed: J42.4, MX31.2 (ROW)
unnamed: J44.1, MX1.2 (ROW)
unnamed: J44.2, MX4.2 (ROW)
unnamed: J44.3, MX7.2 (ROW)
unnamed: J44.4, MX11.2 (ROW)
unnamed: J53.1, MX59.1 (COL), MX62.1 (COL), MX65.1 (COL)
unnamed: J53.2, MX59.2 (ROW)
unnamed: J53.3, MX65.2 (ROW)
unnamed: J53.4, MX62.2 (ROW)
unnamed: J54.1, MX60.1 (COL), MX63.1 (COL), MX66.1 (COL)
unnamed: J54.2, MX60.2 (ROW)
unnamed: J54.3, MX66.2 (ROW)
unnamed: J54.4, MX63.2 (ROW)
unnamed: J55.1, MX61.1 (COL), MX64.1 (COL), MX67.1 (COL)
unnamed: J55.2, MX61.2 (ROW)
unnamed: J55.3, MX67.2 (ROW)
unnamed: J55.4, MX64.2 (ROW)
unnamed: J56.1, MX68.2 (ROW)
unnamed: J56.2, MX71.2 (ROW)
unnamed: J56.3, MX74.2 (ROW)
unnamed: J56.4, MX68.1 (COL), MX71.1 (COL), MX74.1 (COL)
unnamed: J57.1, MX69.2 (ROW)
unnamed: J57.2, MX72.2 (ROW)
unnamed: J57.3, MX75.2 (ROW)
unnamed: J57.4, MX69.1 (COL), MX72.1 (COL), MX75.1 (COL)
unnamed: J58.1, MX70.2 (ROW)
unnamed: J58.2, MX73.2 (ROW)
unnamed: J58.3, MX76.2 (ROW)
unnamed: J58.4, MX70.1 (COL), MX73.1 (COL), MX76.1 (COL)
QSPI_SCLK: IC1.52 (QSPI_SCLK), IC2.6 (CLK)
QSPI_SD0: IC1.53 (QSPI_SD0), IC2.5 (DI_(IO0))
QSPI_SD1: IC1.55 (QSPI_SD1), IC2.2 (DO_(IO1))
QSPI_SD2: IC1.54 (QSPI_SD2), IC2.3 (~WP_(IO2))
QSPI_SD3: IC1.51 (QSPI_SD3), IC2.7 (~HOLD_OR_~/RESET_(IO3))
QSPI_SSN: IC1.56 (QSPI_SS_N), IC2.1 (~CS), R3.2, R7.1
R-TIP: IC3.32 (GPIO21), J46.3, R5.1
RD+: J37.A6 (D+), J37.B6 (D+), R14.2
RD-: J37.A7 (D-), J37.B7 (D-), R15.2
RQSPI_SCLK: IC3.52 (QSPI_SCLK), IC4.6 (CLK)
RQSPI_SD0: IC3.53 (QSPI_SD0), IC4.5 (DI_(IO0))
RQSPI_SD1: IC3.55 (QSPI_SD1), IC4.2 (DO_(IO1))
RQSPI_SD2: IC3.54 (QSPI_SD2), IC4.3 (~WP_(IO2))
RQSPI_SD3: IC3.51 (QSPI_SD3), IC4.7 (~HOLD_OR_~/RESET_(IO3))
RQSPI_SSN: IC3.56 (QSPI_SS_N), IC4.1 (~CS), R12.2, R13.1
RXIN: C21.1, IC3.20 (XIN), Y2.2
RXOUT: IC3.21 (XOUT), R16.1
XIN: C4.1, IC1.20 (XIN), Y1.2
XOUT: IC1.21 (XOUT), R6.1

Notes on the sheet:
As in Planck/rev4: #define MATRIX_ROW_PINS { D3, D5, B5, B6 } #define MATRIX_COL_PINS { F1, F0, B0, C7, F4, F5, F6, F7, D4, D6, B4, D7 } #define DIODE_DIRECTION COL2ROW
This key is linke only to suppress the error on the overlapping pads. The pin is not used
=- Pattern
- - _ Extra key in the middle finger column
_-- Extra key over the inner edge

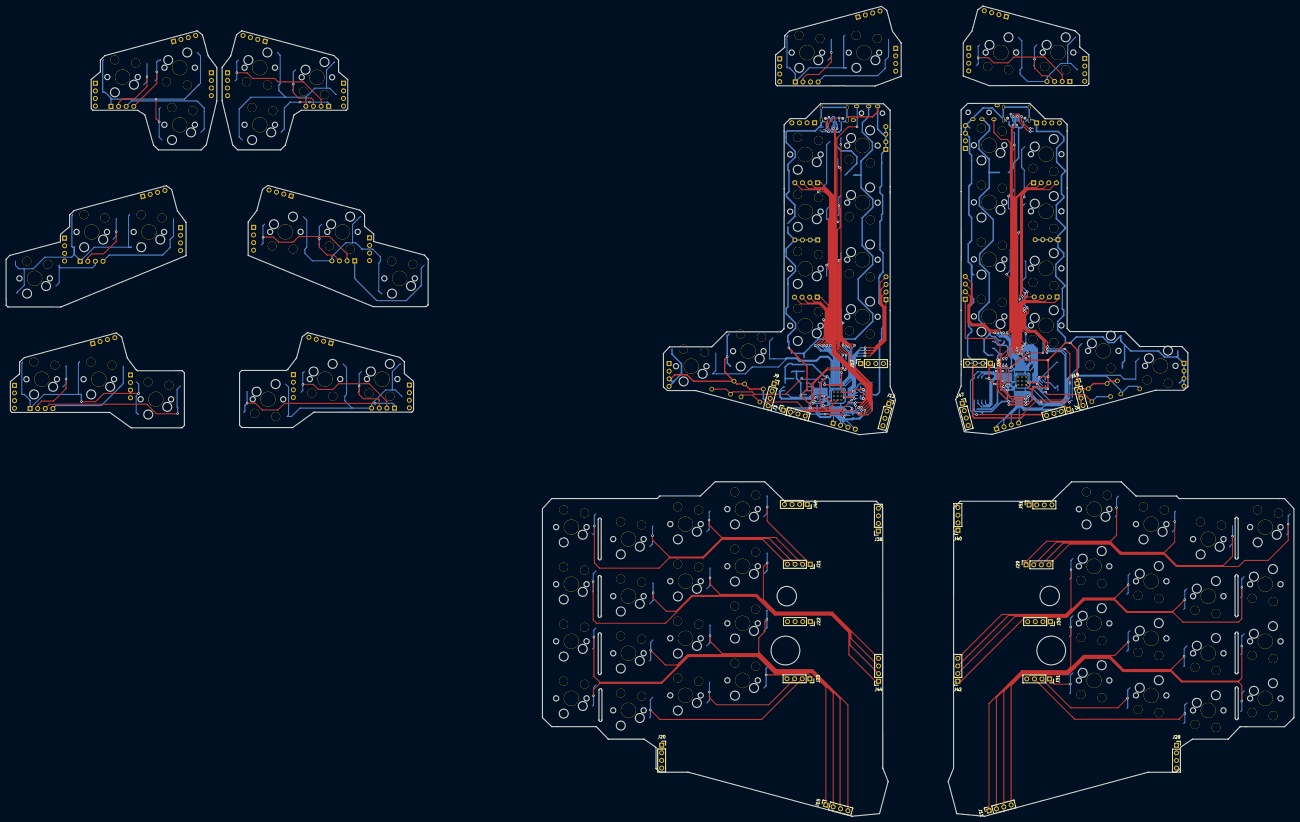
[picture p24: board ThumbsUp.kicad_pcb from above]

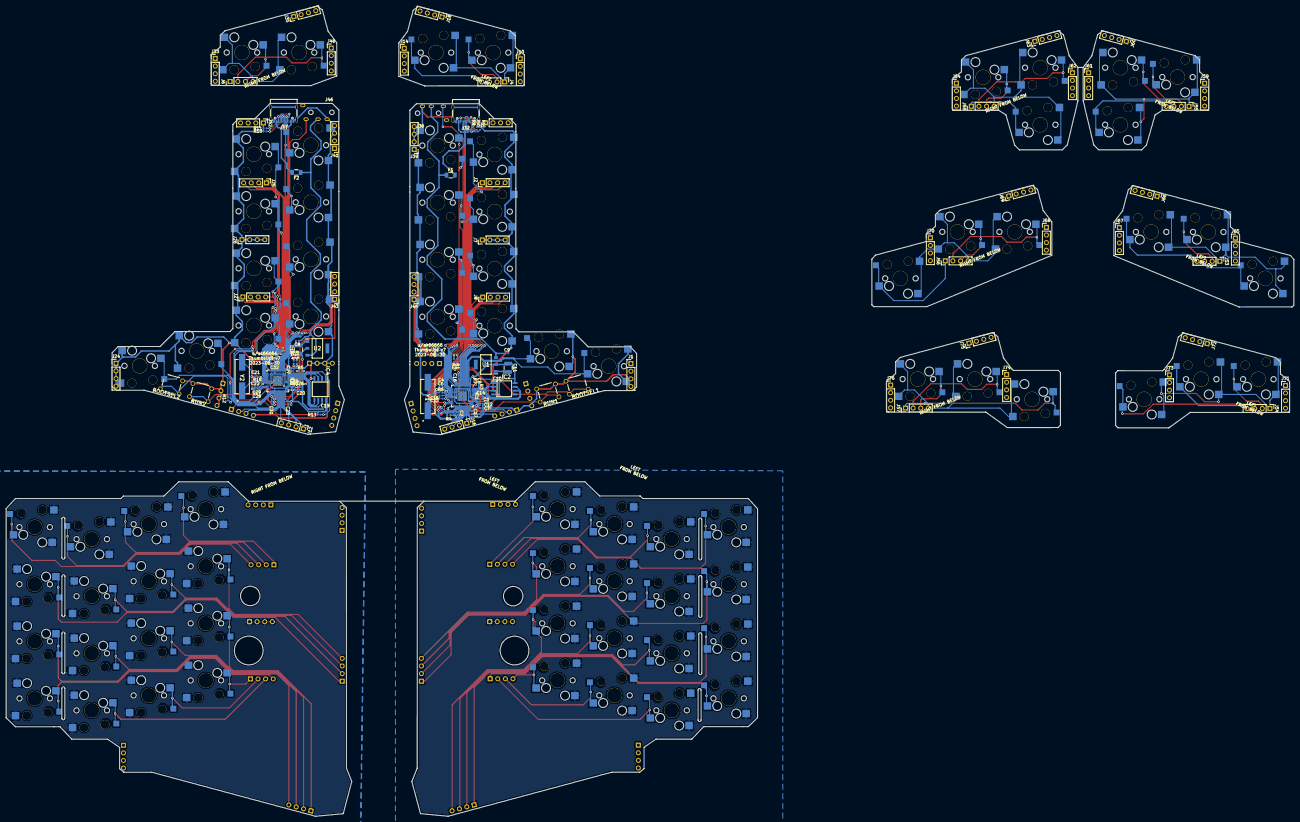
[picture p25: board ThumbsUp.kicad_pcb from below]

Board: 2 copper layers, 429.9 x 270.5 mm, 210 parts (112 on the bottom side), 163 nets.

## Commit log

2023-08-26 Created v7 from v4
    [105450-0101.stp, 52559-1233.stp, 525591233.psm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]
2023-08-27 Wired both RP2040s
    [ThumbsUp.kicad_pcb]
2023-08-31 Layed out tracks on L2
    [ThumbsUp.kicad_pcb, ThumbsUp.sch]
2023-09-02 Layed out tracks on R2
    [ThumbsUp.kicad_pcb, ThumbsUp.sch]
2023-09-02 Layed out tracks on the bottom level havles
    [ThumbsUp.kicad_pcb]
2023-09-03 Adding the 3key thumbclusters
    [ThumbsUp.kicad_pcb, ThumbsUp.sch]
2023-09-04 Tracedd the 3key thumbclusters
    [ThumbsUp.kicad_pcb, ThumbsUp.sch]
2023-09-09 Put the silkscreens on, ready for Gerbers creation
    [ThumbsUp.kicad_pcb]
2023-09-09 Gerber files generated
    [BOM v4 L2.xls, ThumbsUp L2.csv, ThumbsUp R2 BOM.csv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]
2023-10-05 Updated BOMs, Gerbers.
    [BOM L2 20230802.xls, ThumbsUp.kicad_pcb, ThumbsUp.sch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]
2023-10-24 Corrected switch footprint for Gateron sockets
    [ThumbsUp.kicad_pcb, ThumbsUp.step]
2025-02-27 ThumbsUp v7: Added photos, updated description.
    [Case v7 v5.3mf, Case v7 v5.f3d, Case v7 v5.ipt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]
